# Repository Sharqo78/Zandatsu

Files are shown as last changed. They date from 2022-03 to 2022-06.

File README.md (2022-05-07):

# Zandatsu Fighting Controller v1.0

# Introduction
As my first electronics project and as a fighting game player, I've decided to build this controller.
It's a small Mixbox-style controller running with a Raspberry Pi Pico and GP2040 at its core.
It is using MX-Style switches and Kailh hotswap sockets.

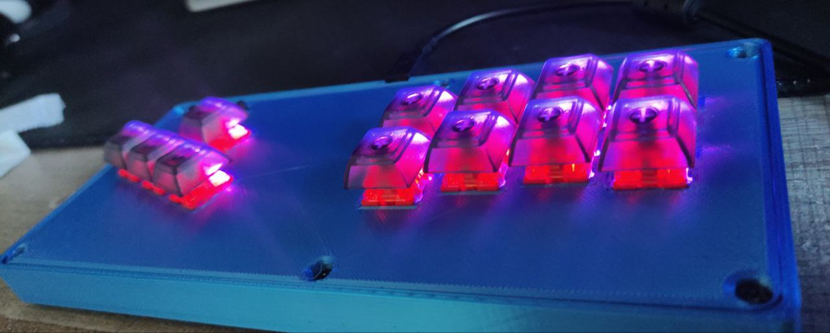
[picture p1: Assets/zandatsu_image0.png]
Preview


# Credits
- FeralAI and sleepunit for the awesome GP2040 firmware and the help they gave me through this project
- My electronics and physics professor
- Guydog because I wouldn't even have known that the OpenStick Discord server and GP2040 existed without him
- The OpenStick Discord for the feedback

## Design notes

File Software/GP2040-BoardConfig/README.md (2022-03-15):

# GP2040 Configuration for Zandatsu
So here's the Zandatsu's boardconfig

## Button Mapping

| Button 	| Pin 	|
|---	|-----	|
| Up 	| 2 	|
| Down 	| 3 	|
| Left 	| 4 	|
| Right  	| 5 	|
| B3 	| 6 	|
| B4 	| 7 	|
| R2 	| 8 	|
| L2 	| 9 	|
| B1 	| 10  	|
| B2 	| 11  	|
| R1 	| 12  	|
| L1 	| 13  	|
| S1 	| 17  	|
| S2 	| 20  	|
| A1 	| 16  	|

## LED Settings
LED Pin - `0`
Max Brightness - `100`
LED Layout  - `WASD`
Brightness Steps - `5`
LEDs per Button - `1`

## LED Order

(From left to right)

```
Up > Down > Left > Right > L1 > R1 > B2 > B1 > B3 > B4 > R2 > L2
```

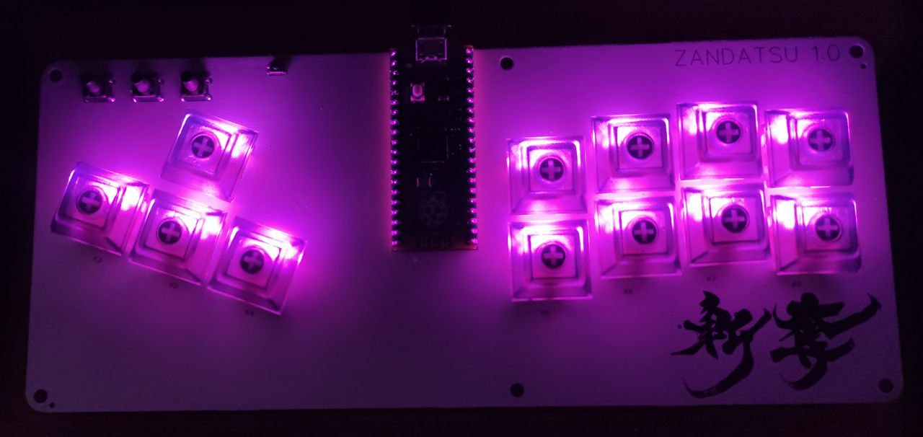
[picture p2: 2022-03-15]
Assets/zandatsu_board.jpg

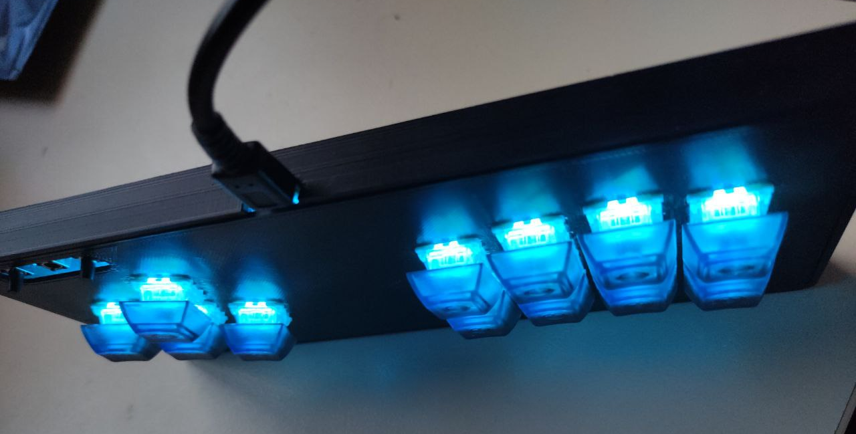
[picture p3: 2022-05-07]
Assets/zandatsu_image1.png

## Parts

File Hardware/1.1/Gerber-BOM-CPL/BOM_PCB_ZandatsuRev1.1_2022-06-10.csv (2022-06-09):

ID | Name | Designator | Footprint | Quantity | Manufacturer Part | Manufacturer | Supplier | Supplier Part | Price
1 | RASPBERRY-PI-PICO_TH/SMT (No Debug Pins) | 1 | RASPBERRY-PI-PICO | 1 |  | Raspberry Pi Foundation | Raspberry Pi | RP2040
2 | MXONLY-1U-HOTSWAP | K1,K2,K3,K4,K5,K6,K7,K8,K9,K10,K11,K12 | MXONLY-1U-HOTSWAP | 12
3 | WS2812B-2020 | LED1,LED2,LED3,LED4,LED5,LED6,LED7,LED8,LED9,LED10,LED11,LED12 | LED-SMD_4P-L2.0-W2.0-TL_WS2812B-2020 | 12 | WS2812B-2020 | Worldsemi | LCSC | C965555 | 0.11
4 | TSA061G90-250 | SW13,SW14,SW15 | SW-TH_4P-L6.0-W6.0-P4.50-LS6.5 | 3 | TSA061G90-250 | BRIGHT | LCSC | C294505 | 0.024
5 | TS-1185EC-C-D-B | SW17 | SW-SMD_4P-L3.7-W3.0-P1.50-LS4.7 | 1 | TS-1185EC-C-D-B | XKB Enterprise | LCSC | C318893 | 0.054

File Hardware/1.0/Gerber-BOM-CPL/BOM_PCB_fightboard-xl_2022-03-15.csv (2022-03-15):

ID | Name | Designator | Footprint | Quantity | Manufacturer Part | Manufacturer | Supplier | Supplier Part | Price
1 | MXONLY-1U-HOTSWAP | K1,K2,K3,K4,K5,K6,K7,K8,K9,K10,K11,K12 | MXONLY-1U-HOTSWAP | 12
2 | TSA061G90-250 | SW13,SW14,SW15 | SW-TH_4P-L6.0-W6.0-P4.50-LS6.5 | 3 | TSA061G90-250 | BRIGHT | LCSC | C294505 | 0.023
3 | TS-1185EC-C-D-B | SW17 | SW-SMD_4P-L3.7-W3.0-P1.50-LS4.7 | 1 | TS-1185EC-C-D-B | XKB Enterprise | LCSC | C318893 | 0.055
4 | RASPBERRY Pi Pico Through Holes | U4 | RASPBERRY PI PICO | 1
5 | WS2812B-2020 | LED1,LED2,LED3,LED4,LED5,LED6,LED7,LED8,LED9,LED10,LED11,LED12 | LED-SMD_4P-L2.0-W2.0-TL_WS2812B-2020 | 12 | WS2812B-2020 | Worldsemi | LCSC | C965555 | 0.156

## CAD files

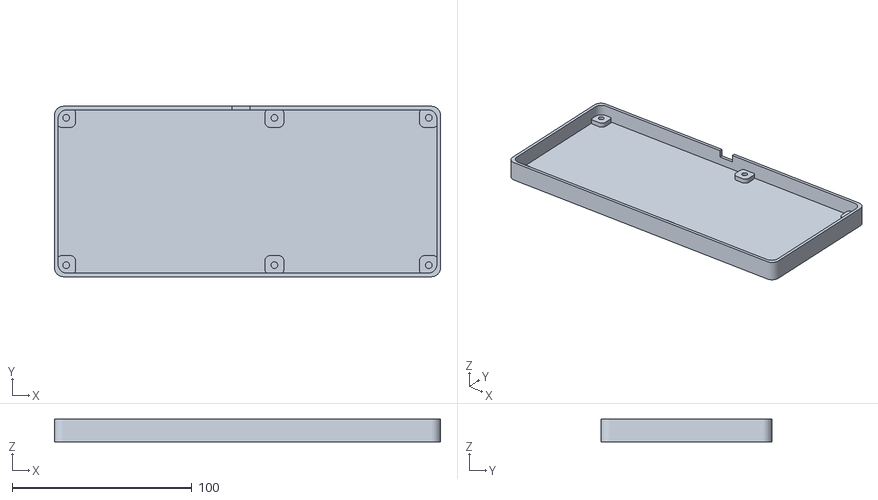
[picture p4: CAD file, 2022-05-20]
Hardware/1.0/3D-Case/zandatsu_case.stl
215.0 x 95.0 x 12.8

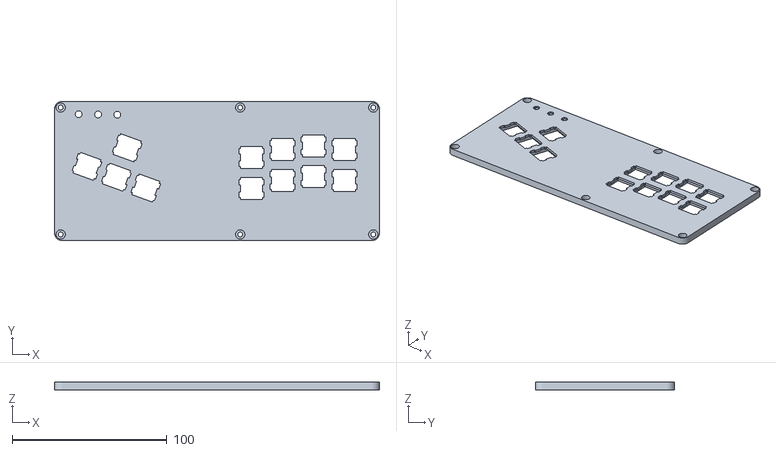
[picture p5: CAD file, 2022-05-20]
Hardware/1.0/3D-Case/frontplate.stl
210.0 x 90.0 x 5.00

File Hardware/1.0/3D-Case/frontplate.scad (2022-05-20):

$fn=75;
szMechanicalSwitch = 14; //Side size

module switchSlot(arrPos, angle=0){
 szMechanicalSwitch = 14.2;
 tabWidth = szMechanicalSwitch+2;
 tabHeight = 3.5;
 
 for(pos = arrPos){
 translate(pos)
  rotate([90, 0, angle]){
   cube(szMechanicalSwitch, center=true);
   translate([0, -6.1, 0])
      cube(19, center=true);
   translate([0, 0, -4.05])
     cube([tabWidth, tabWidth, tabHeight], center=true);
   translate([0, 0, 4.05])
     cube([tabWidth, tabWidth, tabHeight], center=true);
  }
 }
}

module screwSlot(arrPos, diameter=3, wallthickness=2, height=3){
 for(pos = arrPos){
  translate(pos){
   difference(){
    cylinder(h=height, d=diameter+wallthickness, center=true);
    cylinder(h=height+1, d=diameter, center=true);
   }
  }
 } 
}

arrScrewPos = [
 [120, 4, -1.5],
 [120,86, -1.5],
 [206, 4, -1.5],
 [206,86, -1.5],
 [  4, 4, -1.5],
 [  4,86, -1.5]
];


arrWasdPos = [
 [47, 60, 0],
 [21, 48, 0],
 [40, 41, 0],
 [59, 34, 0]
];

posPico = [101, 64, 0];
szPico = [28, 60, 7.5];

arrBtnPos = [
 [127.4, 33.8, 0],
 [127.4, 53.8, 0],
 [147.4, 58.8, 0],
 [147.4, 38.8, 0],
 [167.4, 61.3, 0],
 [167.4, 41.3, 0],
 [187.4, 58.8, 0],
 [187.4, 38.8, 0],
];

arrSecBtnPos = [
 [15.6, 81.7, 0],
 [28.2, 81.5, 0],
 [40.6, 81.4, 0]
];

szSecondaryButtons = 4.4; //Diameter
angleWasd = -20;

roundedCornerDiam = 10;
arrCompRd = [roundedCornerDiam/2, roundedCornerDiam/2];

arrSzPlate = [210-roundedCornerDiam, 90-roundedCornerDiam, 5];

difference(){
 union(){

  translate([roundedCornerDiam/2, roundedCornerDiam/2, 0])
 minkowski(){
  cylinder(d=roundedCornerDiam, h=0.0001, center=false);
  cube(arrSzPlate);
 }
 
}
 
 switchSlot(arrWasdPos, -20);
 switchSlot(arrBtnPos);

 for(secBtnPos = arrSecBtnPos){
   translate(secBtnPos){
    cylinder(d=szSecondaryButtons, h=arrSzPlate.z*2+1 , center=true);
    cube(8, center=true);
   }
}
 
 for(screwPos = arrScrewPos){
    translate(screwPos){
        cylinder(d=3.1, h=arrSzPlate.z*2, center=true);
    }
    translate(screwPos+[0, 0, 5]){
        cylinder(d=6, h=4, center=true);
    }
}
    translate(posPico)
        cube(szPico, center=true);
    translate([61.44, 86.226, 0.5])
        cube([7, 6, 4], center=true);
}
//screwSlot(arrScrewPos, 2.5, 3.5);

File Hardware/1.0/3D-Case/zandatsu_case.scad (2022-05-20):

$fn=70;

iWallThickness = 2;

arrSzPCB = [210, 90, 1.6];
arrBackplaneDiffXY = [iWallThickness*2+1, iWallThickness*2+1, 0];
arrErrorMargin = [1, 1, 1];

iRoundedCornerDiam = 10;
arrRoundedCornerOffset = [iRoundedCornerDiam, iRoundedCornerDiam, 0];

iHeightPylone = 3;
iDiamPylone = 6;
iBackplaneThickness = 3;
iCaseThickness = iBackplaneThickness + 1.6 + 3 +3.6;
arrSzCase = arrSzPCB+arrBackplaneDiffXY-arrRoundedCornerOffset+[0, 0, iCaseThickness];
arrSzHole = arrSzPCB-arrRoundedCornerOffset+arrErrorMargin+[0, 0, iCaseThickness-iBackplaneThickness+0.1];

iUSBHeight = iHeightPylone+1.6+0.5+iBackplaneThickness;
arrUSBSize= [10, 20, 6];


arrScrewPos = [
 [120, 4, -1.5],
 [120,86, -1.5],
 [206, 4, -1.5],
 [206,86, -1.5],
 [  4, 4, -1.5],
 [  4,86, -1.5]
];

arrUSBPos = [arrScrewPos[0].x-19+3, 99,  iUSBHeight];

translate(arrRoundedCornerOffset)
    difference(){
        difference(){
            minkowski(){
             cube(arrSzCase);
             cylinder(h=0.000000001, d=iRoundedCornerDiam);
            }
            translate([0, 0, iBackplaneThickness]+arrBackplaneDiffXY/2-arrErrorMargin/2)
                minkowski(){
                    cube(arrSzHole);
                    cylinder(h=0.000001, d=iRoundedCornerDiam);
                }
        translate(arrUSBPos-arrBackplaneDiffXY+[0, 0, 3])
            cube(arrUSBSize, center=true);
    }
}



for(screwPos = arrScrewPos){
   difference(){
       translate(arrRoundedCornerOffset/2+arrBackplaneDiffXY/2+[0, 0, iBackplaneThickness-0.2]+screwPos+[0, 0, 3])
        minkowski(){
        cylinder(h=iHeightPylone, d=iDiamPylone, center=true);
        cube([iDiamPylone/1.3, iDiamPylone/1.3, 0.01], center=true);
        }
       translate(arrRoundedCornerOffset/2+arrBackplaneDiffXY/2+[0, 0, iBackplaneThickness-0.2]+screwPos+[0, 0, 3])
        cylinder(h=iHeightPylone+0.1, d=iDiamPylone/1.6, center=true);
    }
}

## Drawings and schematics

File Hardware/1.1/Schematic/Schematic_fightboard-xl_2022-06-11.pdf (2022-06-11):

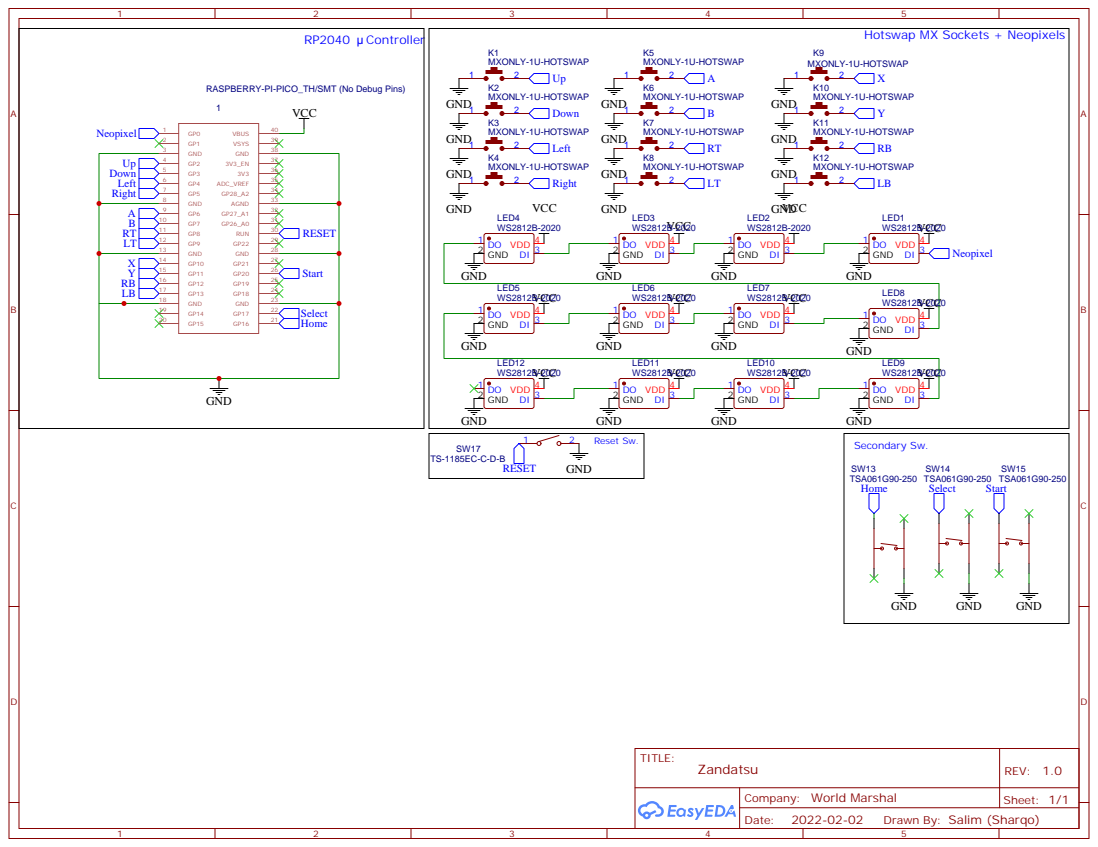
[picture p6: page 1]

RASPBERRY-PI-PICO_TH/SMT (No Debug Pins)

Drawn By: Salim (Sharqo)

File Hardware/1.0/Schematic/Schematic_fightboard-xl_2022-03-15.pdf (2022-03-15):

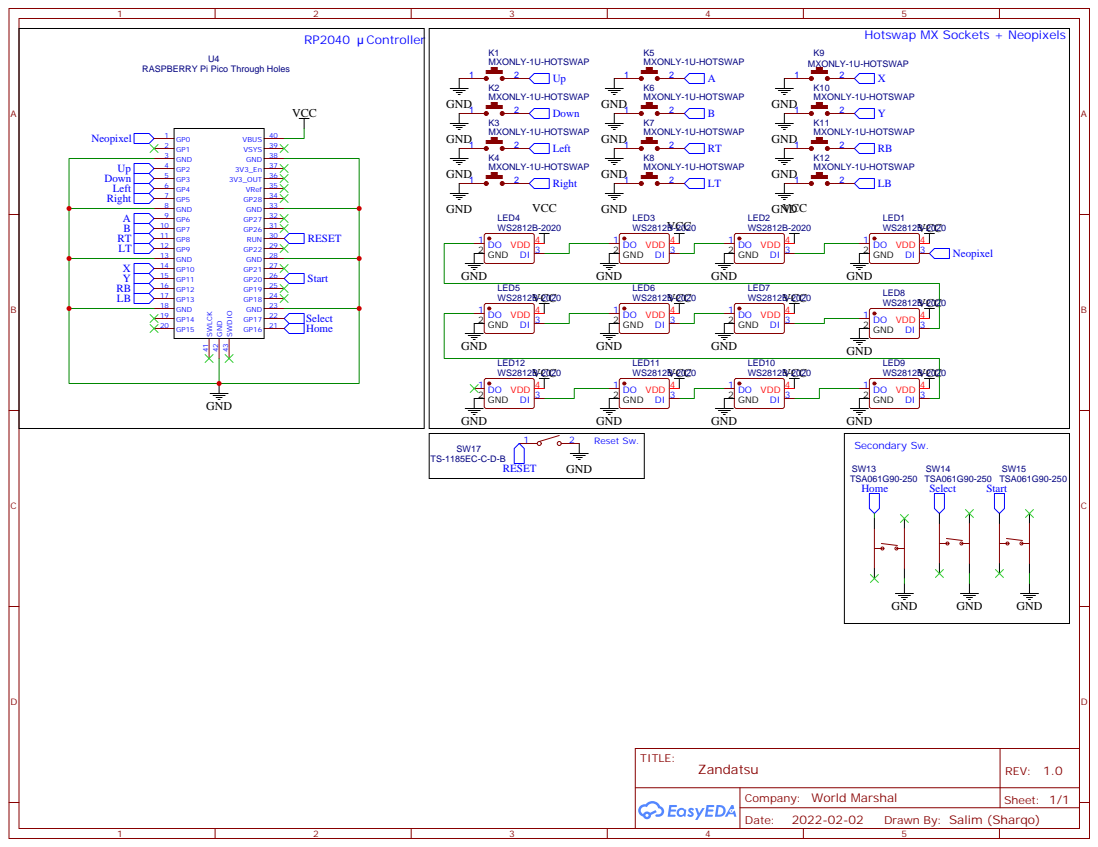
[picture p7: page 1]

RASPBERRY Pi Pico Through Holes

Drawn By: Salim (Sharqo)

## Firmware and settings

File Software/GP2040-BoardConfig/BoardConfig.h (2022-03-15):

/*
 * SPDX-License-Identifier: MIT
 * SPDX-FileCopyrightText: Copyright (c) 2021 Jason Skuby (mytechtoybox.com)
 */

#ifndef PICO_BOARD_CONFIG_H_
#define PICO_BOARD_CONFIG_H_

#include <GamepadEnums.h>


#define BOARD_LEDS_PIN 0

#define LED_BRIGHTNESS_MAXIMUM 100
#define LED_BRIGHTNESS_STEPS 5
#define LED_FORMAT LED_FORMAT_GRB
#define LEDS_PER_PIXEL 1


#define PIN_DPAD_UP     2
#define PIN_DPAD_DOWN   3
#define PIN_DPAD_RIGHT  5
#define PIN_DPAD_LEFT   4
#define PIN_BUTTON_B1   6
#define PIN_BUTTON_B2   7
#define PIN_BUTTON_R2   8
#define PIN_BUTTON_L2   9
#define PIN_BUTTON_B3   10
#define PIN_BUTTON_B4   11
#define PIN_BUTTON_R1   12
#define PIN_BUTTON_L1   13
#define PIN_BUTTON_S1   17
#define PIN_BUTTON_S2   20
#define PIN_BUTTON_L3   18
#define PIN_BUTTON_R3   19
#define PIN_BUTTON_A1   16
#define PIN_BUTTON_A2   -1

#define DEFAULT_SOCD_MODE SOCD_MODE_NEUTRAL
#define BUTTON_LAYOUT BUTTON_LAYOUT_WASD


#define LED_BRIGHTNESS_MAXIMUM 100
#define LED_BRIGHTNESS_STEPS 5
#define LED_FORMAT LED_FORMAT_GRB
#define LEDS_PER_PIXEL 1

#define BUTTON_LAYOUT BUTTON_LAYOUT_WASD
#define BOARD_LEDS_PIN 0

#define LEDS_DPAD_UP     0
#define LEDS_DPAD_DOWN   1
#define LEDS_DPAD_LEFT   2
#define LEDS_DPAD_RIGHT  3
#define LEDS_BUTTON_L2   4
#define LEDS_BUTTON_R2   5
#define LEDS_BUTTON_B2   6
#define LEDS_BUTTON_B1   7
#define LEDS_BUTTON_B3   8
#define LEDS_BUTTON_B4   9
#define LEDS_BUTTON_R1   10
#define LEDS_BUTTON_L1   11

#endif

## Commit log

2022-03-15 the pdf had incorrect button pinout
2022-05-07 huge changes + case made
    [BOM_PCB_fightboard-xl_2022-03-15.csv, PickAndPlace_PCB_fightboard-xl_2022-03-15.csv, frontplate.scad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]
2022-05-20 Updated the case to a sturdier one
    [frontplate.scad, frontplate.stl, zandatsu_case.scad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]
2022-06-09 Added 1.1 board
    [BOM_PCB_ZandatsuRev1.1_2022-06-10.csv, PickAndPlace_PCB_ZandatsuRev1.1_2022-06-10.csv]
2022-06-11 Added Project and Schematic files 1.1
    [BOM_PCB_ZandatsuRev1.1_2022-06-10.csv, PickAndPlace_PCB_ZandatsuRev1.1_2022-06-10.csv]
